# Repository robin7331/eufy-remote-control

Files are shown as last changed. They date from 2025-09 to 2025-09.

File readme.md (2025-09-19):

# Eufy Make Remote Control Button Box

This repository contains both the **software** and **hardware** files for the Eufy Make Remote Control Button Box project.

## Overview

- **Hardware**: Kicad PCB designs
- **Software**: MicroPython code for the RP2040 Stamp

## Connectivity

The button box is designed to connect to an **MQTT broker**.

---

For details, see the `hardware/` and `software/` folders.

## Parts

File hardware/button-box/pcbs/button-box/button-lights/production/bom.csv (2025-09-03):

Designator | Footprint | Quantity | Value | LCSC Part #
J1, J2 | CONN_SM04B-SRSS-TB_JST | 2 | SM04B-SRSS-TB
U1, U2, U3, U4 | LED_WS2812-2020 | 4 | WS2812-2020

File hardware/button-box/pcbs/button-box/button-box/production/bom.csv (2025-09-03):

Designator | Footprint | Quantity | Value | LCSC Part #
C1 | 0603 | 1 | 1n | 1n 0603
C2 | 0603 | 1 | 100n | 100n 0603
C3 | 0805 | 1 | 10u
D1, D2, D3 | SOT-23 | 3 | SP0502BAHT | SP0502BAHT
F1 | 1812 | 1 | 1812L150/24 | 1812L075PR
J1 | USB_C_Purple | 1 | HC-TYPE-C-16P-01A-L
J2 | CONN_SM04B-SRSS-TB_JST | 1 | SM04B-SRSS-TB
J3 | PinHeader_1x03_P2.54mm_Horizontal | 1 | Conn_01x03_Pin
L1 | L_TDK_SLF7032 | 1 | 6.8uH | SLF7032T-6R8M1R6-2-PF
Q1, Q2 | SOT-23 | 2 | onsemi NTR4503NT1G | NTR4503NT1G
R1, R11, R13, R5 | 0603 | 4 | 10k | 10k 0603
R10 | 0603 | 1 | 470 | 1M 0603
R12 | 0603 | 1 | 10k | 1M 0603
R2 | 0603 | 1 | 1M | 1M 0603
R3, R4 | 0603 | 2 | 0
R6, R8 | 0603 | 2 | 12k | 1M 0603
R7 | 0603 | 1 | 5.1k | 5.1k 0402
R9 | 0603 | 1 | 5.1k | 5.1k 0603
SW1, SW2 | SW_MX_LowProfile_THT | 2 | SW_Push
U1 | rpi_rmc20452t | 1 | RP Wireless Module 2
U2 | RP2xxx_Stamp_SMD | 1 | RP2040_Stamp

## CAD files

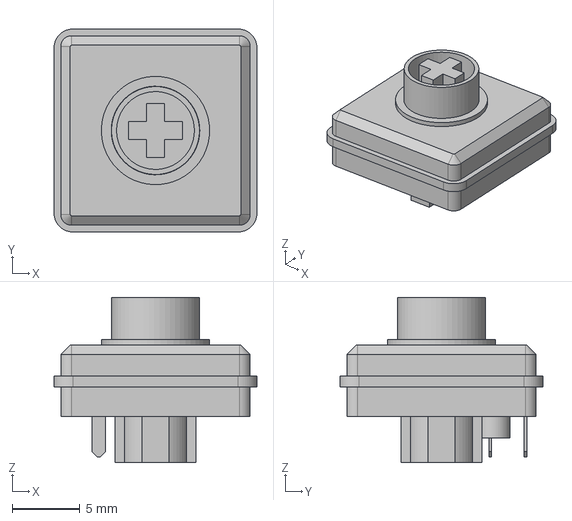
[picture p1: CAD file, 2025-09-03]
hardware/button-box/pcbs/button-box/button-box/components/cherry-mx-low-profile/[low detail] Low Profile Cherry MX Red.step
15.0 x 15.0 x 12.2 mm

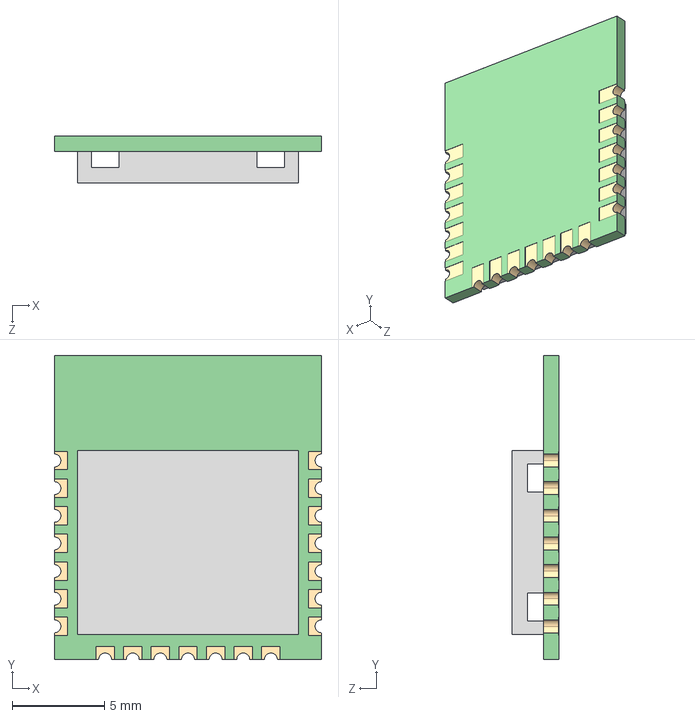
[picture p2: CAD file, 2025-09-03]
hardware/button-box/pcbs/button-box/button-box/components/raspberry-wireless-module-2/3d_models/rpi_rmc20452t.step
14.5 x 16.5 x 2.55 mm

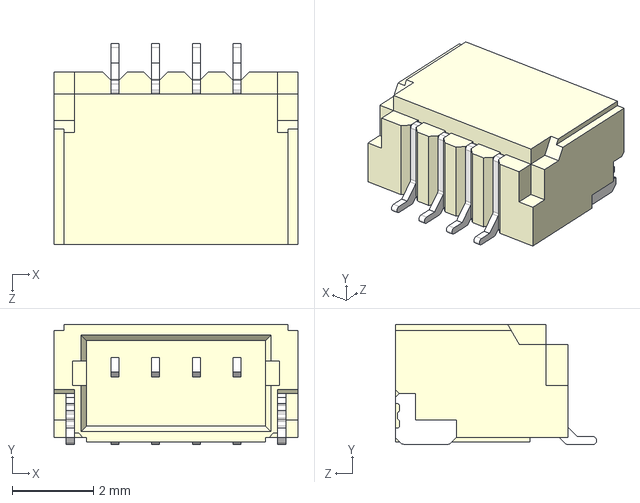
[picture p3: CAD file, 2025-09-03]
hardware/button-box/pcbs/button-box/button-box/components/SM04B-SRSS-TB/SM04B-SRSS-TB.step
6.00 x 2.96 x 4.95 mm

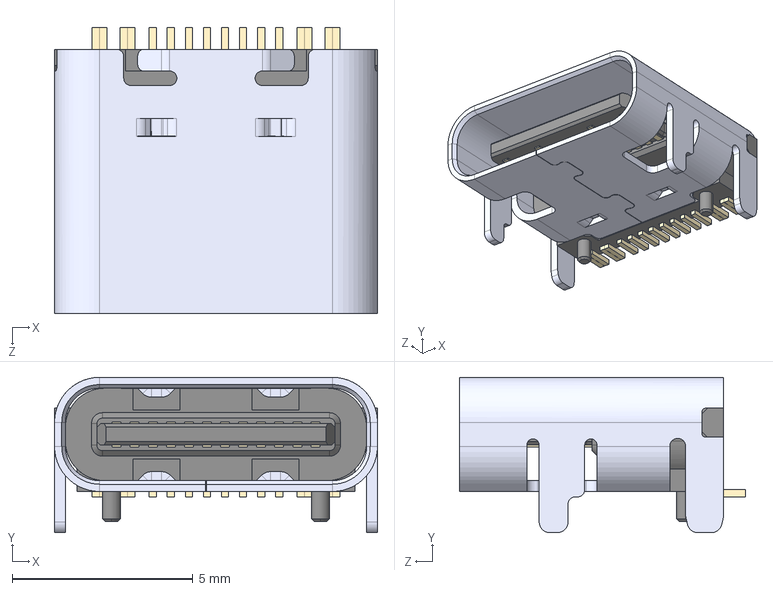
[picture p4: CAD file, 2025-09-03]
hardware/button-box/pcbs/button-box/button-box/components/USB-C/TYPE-C-31-M-12--3DModel-STEP-56544.STEP
8.94 x 4.30 x 7.90 mm

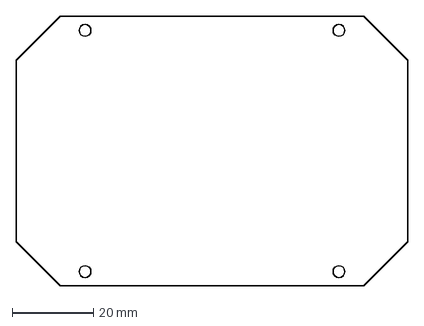
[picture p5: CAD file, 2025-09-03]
hardware/button-box/pcbs/button-box/button-box/fusion-export/Outline.dxf
96.4 x 66.4 mm

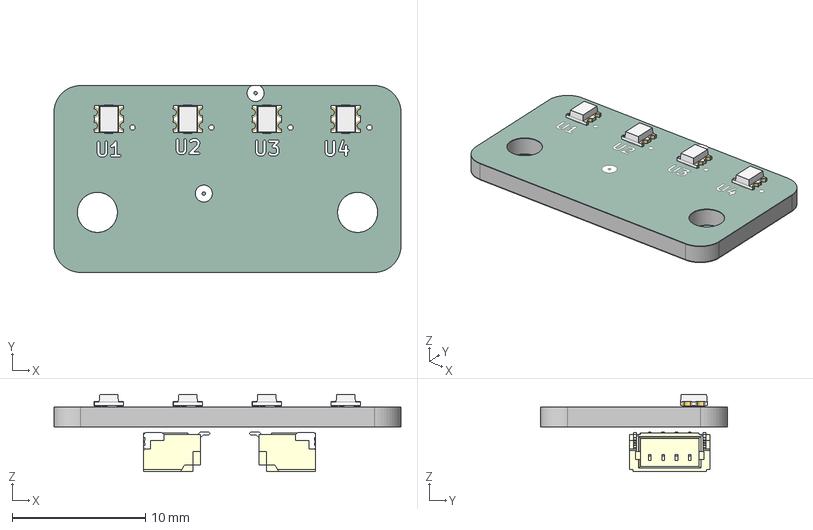
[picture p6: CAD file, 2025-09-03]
hardware/button-box/pcbs/button-box/button-lights/button-lights.step
26.0 x 14.0 x 5.79 mm
WS2812-2020 x 4
SM04B-SRSS-TB x 2
button-lights_silkscreen
button-lights_soldermask
button-lights_PCB

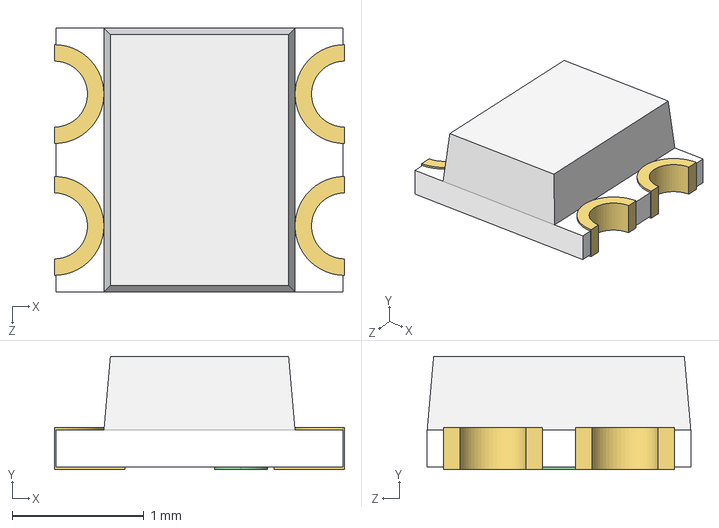
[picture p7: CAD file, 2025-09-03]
hardware/button-box/pcbs/button-box/button-lights/components/WS2812-2020/WS2812-2020.STEP
2.20 x 0.86 x 2.00 mm

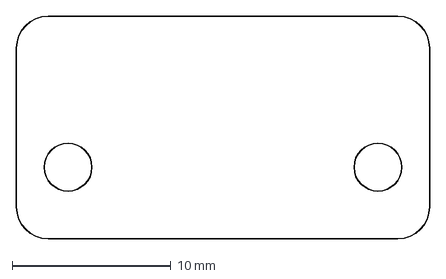
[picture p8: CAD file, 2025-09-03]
hardware/button-box/pcbs/button-box/button-lights/fusion-export/Outline.dxf
26.0 x 14.0 mm

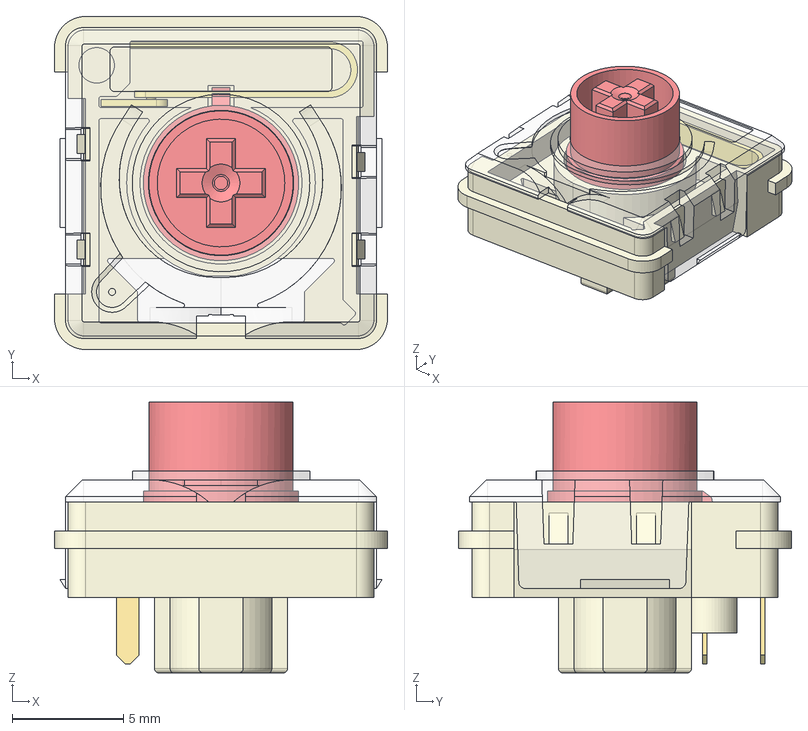
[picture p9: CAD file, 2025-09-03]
hardware/button-box/pcbs/button-box/button-box/components/cherry-mx-low-profile/[high detail] Low Profile Cherry MX Red.step
15.0 x 15.0 x 12.2 mm
Stem
Top Case
Bottom Case
Spring

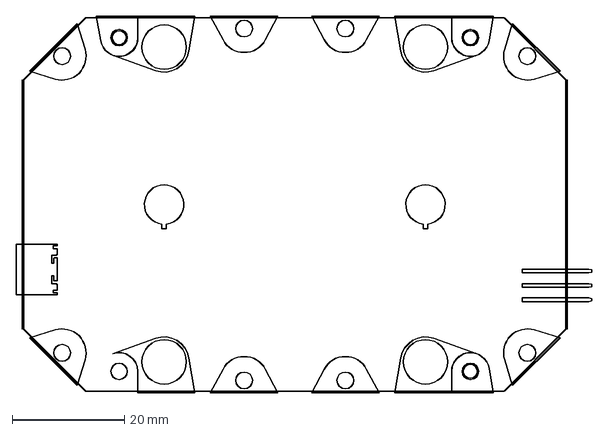
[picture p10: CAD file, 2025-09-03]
hardware/button-box/pcbs/button-box/button-box/fusion-export/User Drawings.dxf
102.4 x 67.0 mm

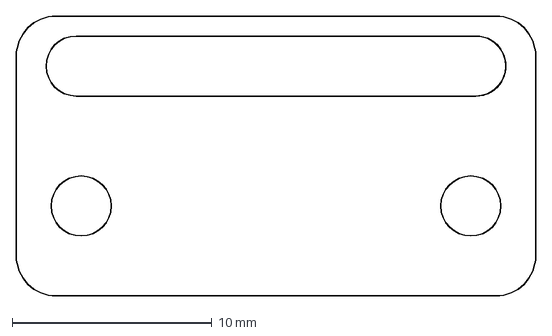
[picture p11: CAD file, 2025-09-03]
hardware/button-box/pcbs/button-box/button-lights/fusion-export/Drawings.dxf
26.0 x 14.0 mm

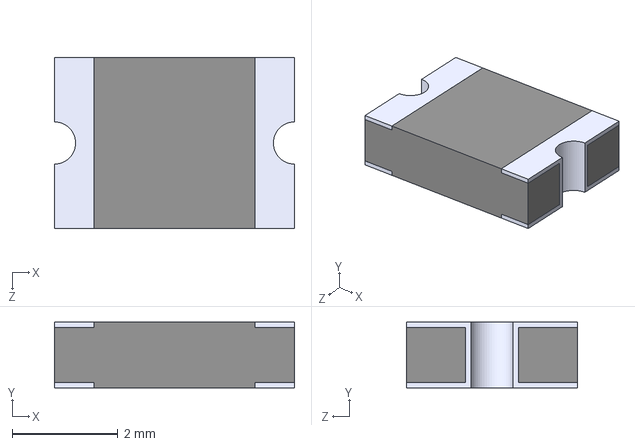
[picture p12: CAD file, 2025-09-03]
hardware/button-box/pcbs/button-box/button-box/components/1812L150_24.STEP
4.55 x 1.25 x 3.24 mm

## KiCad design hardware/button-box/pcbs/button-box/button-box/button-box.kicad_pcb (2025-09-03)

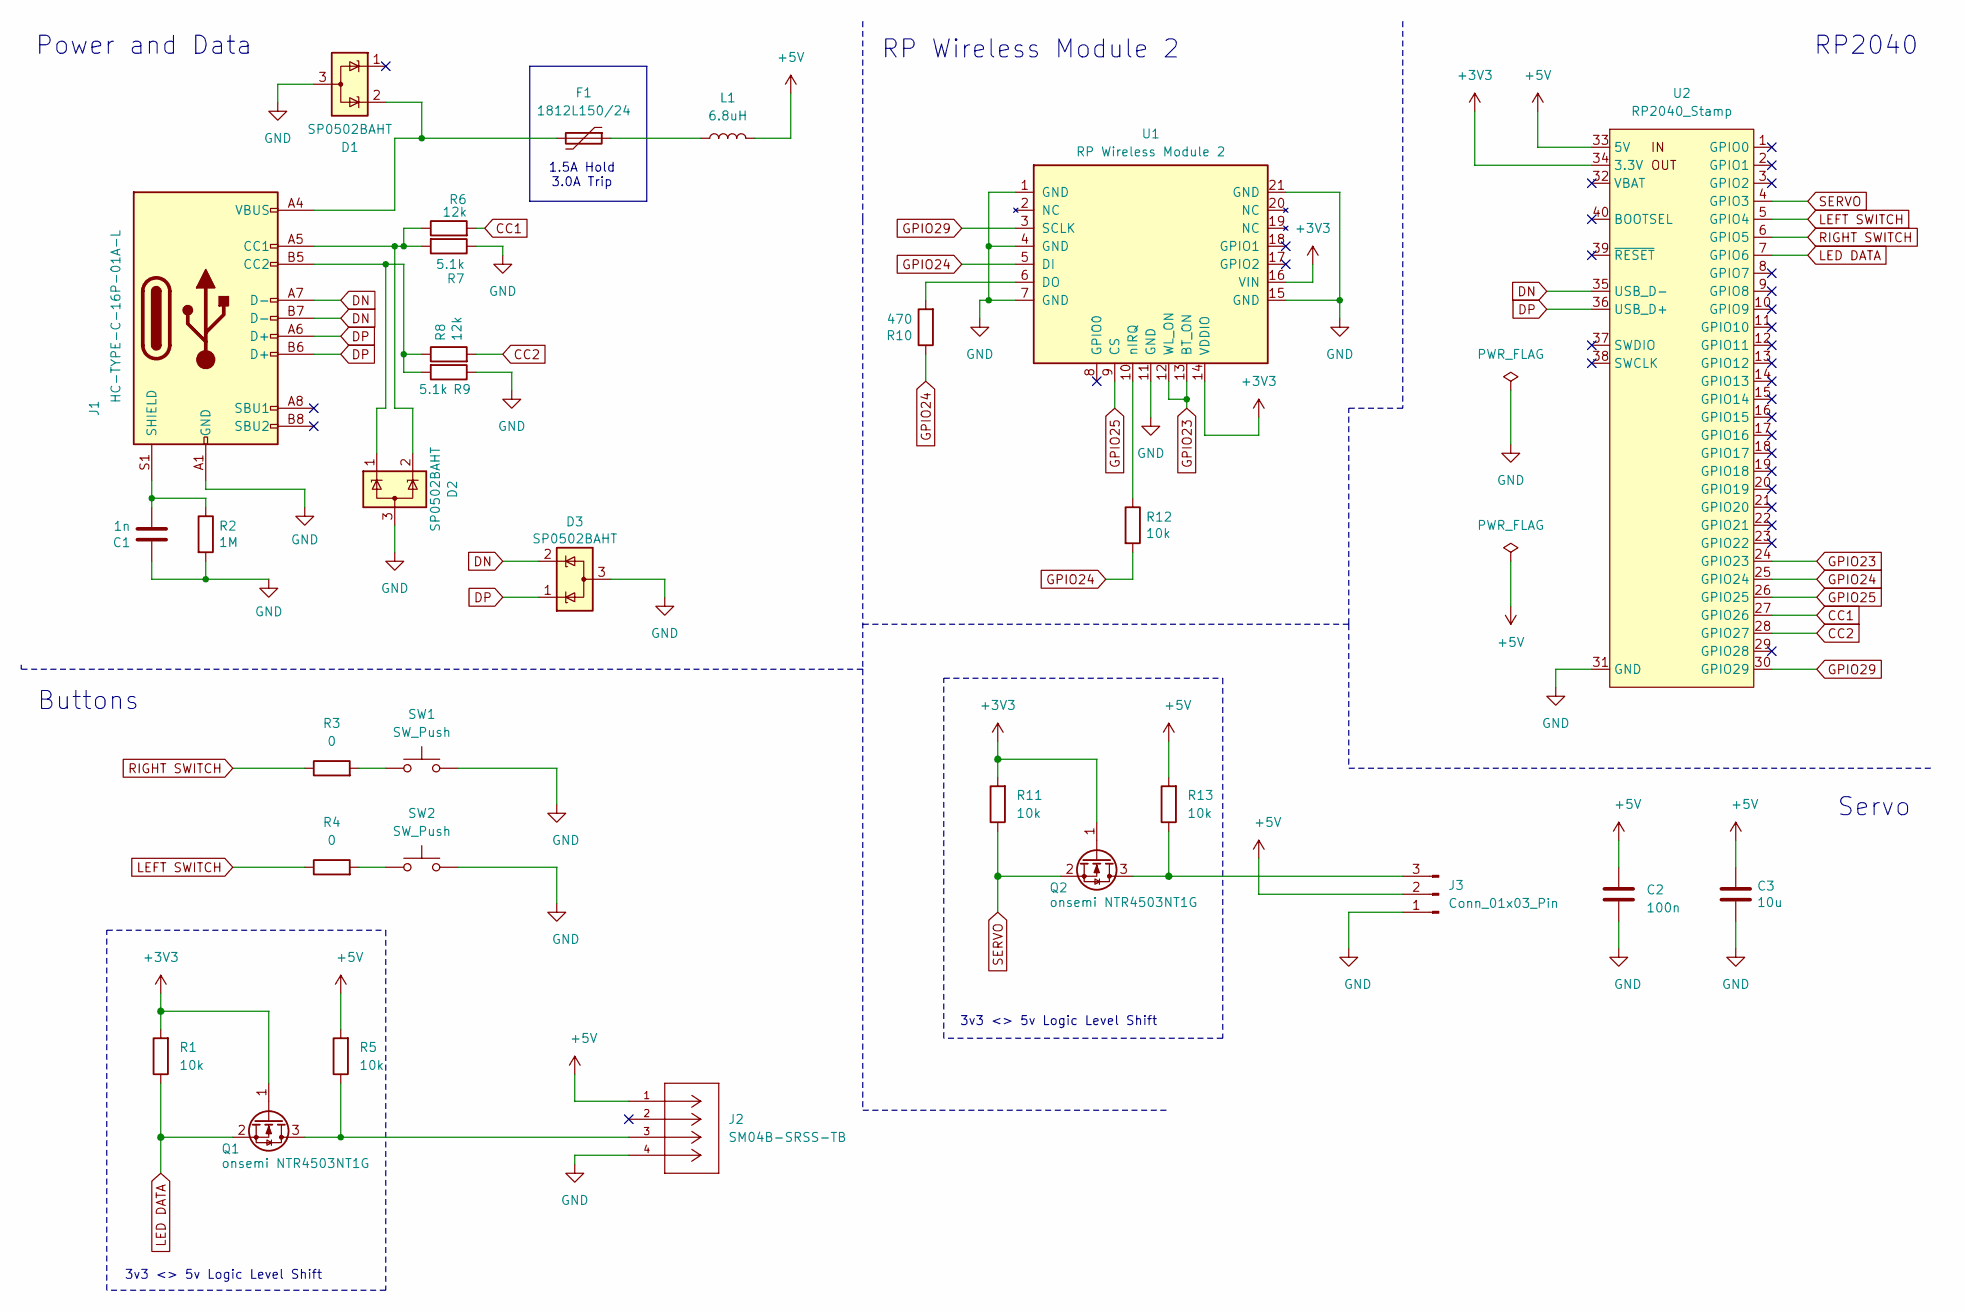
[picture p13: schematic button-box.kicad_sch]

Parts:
C1: 1n; C_0603_1608Metric; MPN 1n 0603
C2: 100n; C_0603_1608Metric; MPN 100n 0603
C3: 10u; C_0805_2012Metric
D1, D2, D3: SP0502BAHT; SOT-23; MPN SP0502BAHT
F1: 1812L150/24; Fuse_1812_4532Metric; MPN 1812L075PR
J1: HC-TYPE-C-16P-01A-L; USB_C_Purple
J2: SM04B-SRSS-TB; CONN_SM04B-SRSS-TB_JST; MANUFACTURER_PART_NUMBER SM04B-SRSS-TB
J3: Conn_01x03_Pin; PinHeader_1x03_P2.54mm_Horizontal
L1: 6.8uH; L_TDK_SLF7032; MPN SLF7032T-6R8M1R6-2-PF
Q1, Q2: onsemi NTR4503NT1G; SOT-23; MPN NTR4503NT1G
R1, R5, R11, R13: 10k; R_0603_1608Metric; MPN 10k 0603
R2: 1M; R_0603_1608Metric; MPN 1M 0603
R3, R4: 0; C_0603_1608Metric
R6, R8: 12k; R_0603_1608Metric; MPN 1M 0603
R7: 5.1k; R_0603_1608Metric; MPN 5.1k 0402
R9: 5.1k; R_0603_1608Metric; MPN 5.1k 0603
R10: 470; R_0603_1608Metric; MPN 1M 0603
R12: 10k; R_0603_1608Metric; MPN 1M 0603
SW1, SW2: SW_Push; SW_MX_LowProfile_THT
U1: RP Wireless Module 2; rpi_rmc20452t
U2: RP2040_Stamp; RP2xxx_Stamp_SMD

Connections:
+3V3: Q1.1 (G), Q2.1 (G), R1.2, R11.2, U1.14 (VDDIO), U1.16 (VIN), U2.34 (3.3V)
+5V: C2.1, C3.1, J2.1, J3.2, L1.2, R5.2, R13.2, U2.33 (5V)
CC1: R6.2, U2.27 (GPIO26)
CC2: R8.2, U2.28 (GPIO27)
DN: D3.2 (K), J1.A7 (D-), J1.B7 (D-), U2.35 (USB_D-)
DP: D3.1 (K), J1.A6 (D+), J1.B6 (D+), U2.36 (USB_D+)
GND: C1.1, C2.2, C3.2, D1.3 (A), D2.3 (A), D3.3 (A), J1.A1 (GND), J1.A12 (GND), J1.B1 (GND), J1.B12 (GND), J2.4, J3.1, R2.2, R7.1, R9.1, SW1.2, SW2.2, U1.1 (GND), U1.4 (GND), U1.7 (GND), U1.11 (GND), U1.15 (GND), U1.21 (GND), U2.31 (GND)
GPIO23: U1.12 (WL_ON), U1.13 (BT_ON), U2.24 (GPIO23)
GPIO24: R10.1, R12.2, U1.5 (DI), U2.25 (GPIO24)
GPIO25: U1.9 (CS), U2.26 (GPIO25)
GPIO29: U1.3 (SCLK), U2.30 (GPIO29)
LED DATA: Q1.2 (S), R1.1, U2.7 (GPIO6)
LEFT SWITCH: R4.1, U2.5 (GPIO4)
unnamed: D1.2 (K), F1.2, J1.A4 (VBUS), J1.A9 (VBUS), J1.B4 (VBUS), J1.B9 (VBUS)
unnamed: F1.1, L1.1
unnamed: D2.2 (K), J1.A5 (CC1), R6.1, R7.2
unnamed: D2.1 (K), J1.B5 (CC2), R8.1, R9.2
unnamed: C1.2, J1.S1 (SHIELD), R2.1
unnamed: J3.3, Q2.3 (D), R13.1
unnamed: J2.3, Q1.3 (D), R5.1
unnamed: R3.2, SW1.1
unnamed: R4.2, SW2.1
unnamed: R10.2, U1.6 (DO)
unnamed: R12.1, U1.10 (nIRQ)
RIGHT SWITCH: R3.1, U2.6 (GPIO5)
SERVO: Q2.2 (S), R11.1, U2.4 (GPIO3)

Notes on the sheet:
3v3 <> 5v Logic Level Shift
RP2040
Power and Data
Servo
Buttons
RP Wireless Module 2
1.5A Hold 3.0A Trip

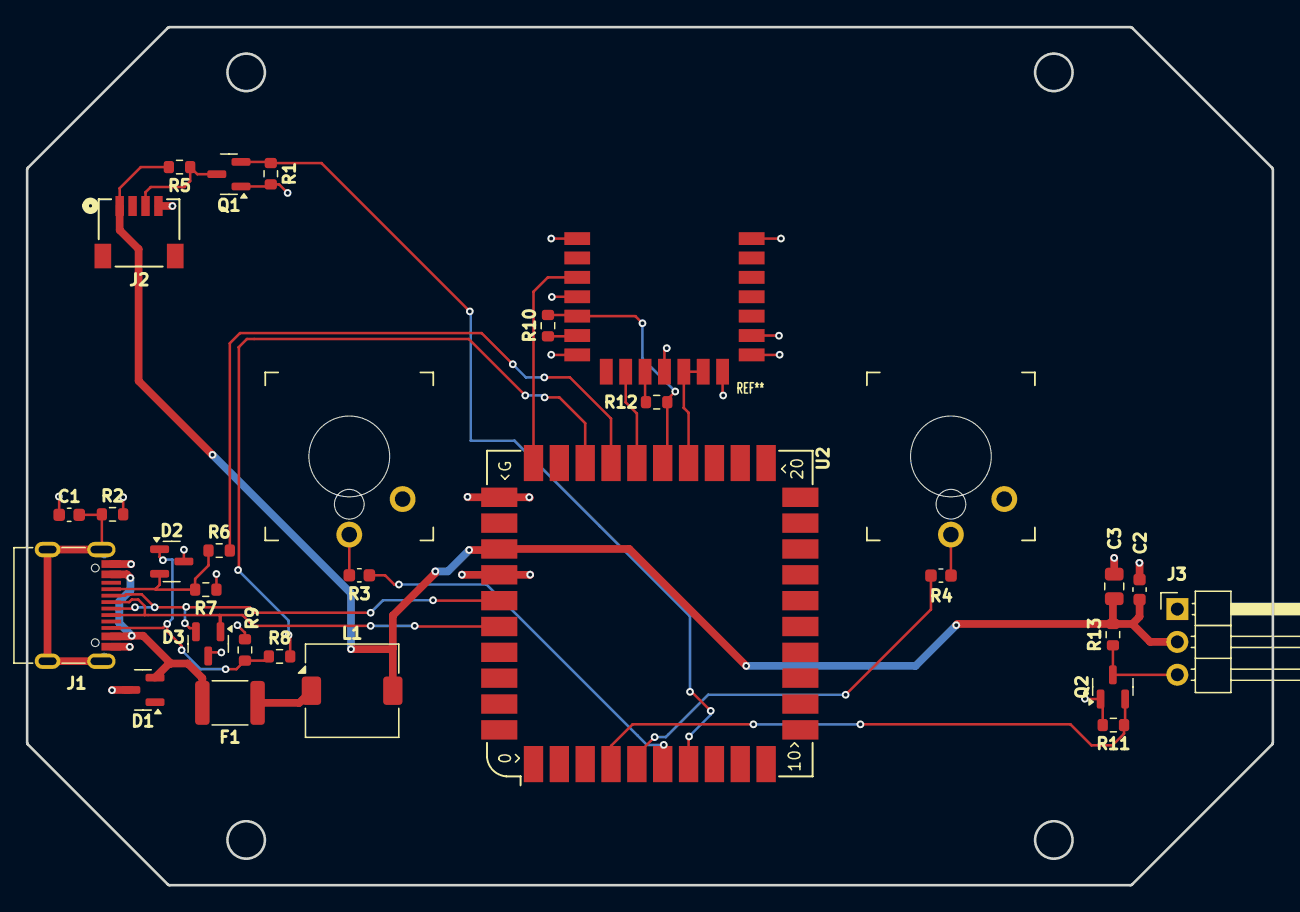
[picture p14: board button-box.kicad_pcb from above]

Board: 4 copper layers, 96.4 x 66.4 mm, 30 parts (0 on the bottom side), 26 nets.

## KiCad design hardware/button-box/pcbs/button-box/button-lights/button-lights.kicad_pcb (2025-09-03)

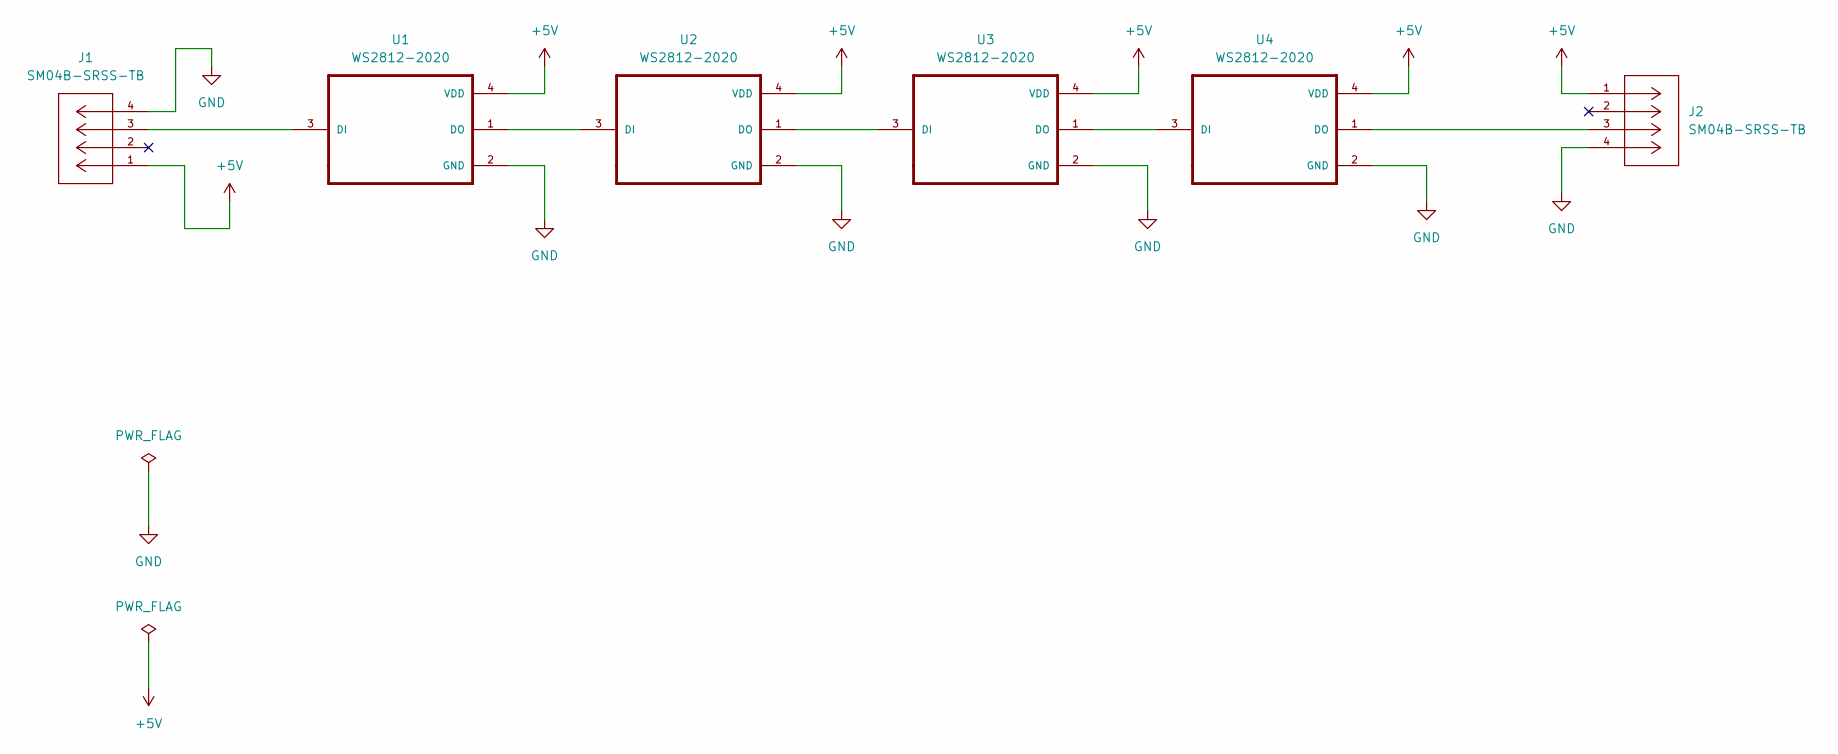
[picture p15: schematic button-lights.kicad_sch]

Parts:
J1, J2: SM04B-SRSS-TB; CONN_SM04B-SRSS-TB_JST; MANUFACTURER_PART_NUMBER SM04B-SRSS-TB
U1, U2, U3, U4: WS2812-2020; LED_WS2812-2020

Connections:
+5V: J1.1, J2.1, U1.4 (VDD), U2.4 (VDD), U3.4 (VDD), U4.4 (VDD)
GND: J1.4, J2.4, U1.2 (GND), U2.2 (GND), U3.2 (GND), U4.2 (GND)
unnamed: J1.3, U1.3 (DI)
unnamed: U1.1 (DO), U2.3 (DI)
unnamed: U2.1 (DO), U3.3 (DI)
unnamed: U3.1 (DO), U4.3 (DI)
unnamed: J2.3, U4.1 (DO)

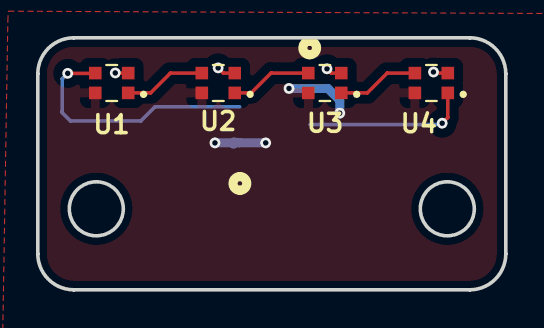
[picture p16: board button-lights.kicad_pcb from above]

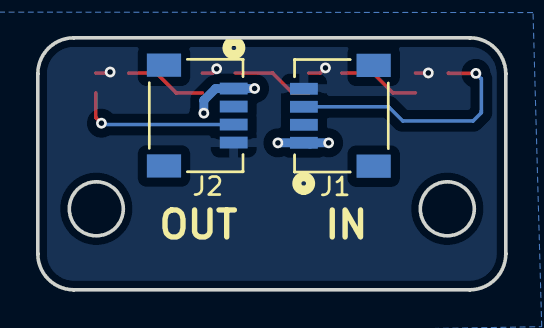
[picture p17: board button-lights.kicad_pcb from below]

Board: 2 copper layers, 26.0 x 14.0 mm, 6 parts (2 on the bottom side), 7 nets.

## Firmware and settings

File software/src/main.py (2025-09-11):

import machine

from time import sleep
import machine
import ujson
from ui_renderer import UIRenderer
from boot_sequence import run_boot_sequence
from machine import Timer
import utime
from controls.io_event_source import IOEventSource
from controls.io_event import IOEvent
from controls.illumination import Illumination
from controls.tapper import Tapper
from device import Device
from connection_manager import ConnectionManager, ConnectionState, PingState
import asyncio


# MQTT Broker details
BROKER_IP = '192.168.4.167'
BROKER_PORT = 1883
STATUS_TOPIC = 'uv_studio/status'
COMMAND_TOPIC = 'uv_studio/command'
CONTROL_TOPIC = 'uv_studio/control'

machine.freq(96000000)

# The UI Renderer class holds the frame buffer and the PIO state machine
renderer = UIRenderer(brightness_modifier=1.0, led_pin=6, led_count=8)



# Lets render the buttons at 30 fps (just for the boot sequence)
uiTimer = Timer()
uiTimer.init(freq=30, mode=Timer.PERIODIC,
             callback=lambda t: renderer.flush_frame_buffer())
# # Lets run a fancy rainbow boot sequence
run_boot_sequence(renderer, led_count=8, brightness=0.8)
uiTimer.deinit()


def renderIllumination(entity):
    global renderer
    for led_index in entity.led_indexes:
        renderer.set_led_color(
            led_index, (entity.color[0], entity.color[1], entity.color[2]), entity.color[3])

left_button_illumination = Illumination(led_indexes=[4,5,6,7], on_should_render=renderIllumination)    
right_button_illumination = Illumination(led_indexes=[0,1,2,3], on_should_render=renderIllumination)    

left_button_illumination.set_color((0, 0, 0), 0.0, animated=False)
right_button_illumination.set_color((0, 0, 0), 0.0, animated=False)

tapper = Tapper()

device = Device(left_illumination=left_button_illumination, right_illumination=right_button_illumination, tapper=tapper)



def connection_cb(connection_manager, state):
    print('Connection state changed to: %s' % state)
    if state is ConnectionState.ERROR:
        device.to_error()

def on_ping(connection_manager, state):
    print('Ping state changed to: %s' % state)
    if state is PingState.PRINTING_12MM:
        device.to_printing(type='12mm')

    if state is PingState.PRINTING_16MM:
        device.to_printing(type='16mm')

    if state is PingState.ERROR_12MM:
        device.to_error(type='12mm')

    if state is PingState.ERROR_16MM:
        device.to_error(type='16mm')

    if state is PingState.TIMEOUT:
        device.to_timeout()

    if state is PingState.IDLE: 
        device.to_idle()


def left_button_tapped(source):
    global connection_manager
    if device.is_idle() or device.is_error():
        connection_manager.send_mqtt_command('start_12mm_print')
    else: 
        print('Not in idle state, ignoring button press')


def right_button_tapped(source):
    global connection_manager
    if device.is_idle() or device.is_error():
        connection_manager.send_mqtt_command('start_16mm_print')
    else: 
        print('Not in idle state, ignoring button press')

def stop(source):
    global connection_manager
    connection_manager.send_mqtt_command('stop')

def set_tapper_parameters(retracted_angle, extended_angle):
    tapper.retracted_angle = retracted_angle
    tapper.extended_angle = extended_angle


left_button = IOEventSource(title='Left Button', pin_number=4, pin_mode=machine.Pin.IN, pin_pull=machine.Pin.PULL_UP, invert=True, on_tapped=left_button_tapped, on_long_hold=stop)
right_button = IOEventSource(title='Right Button', pin_number=5, pin_mode=machine.Pin.IN, pin_pull=machine.Pin.PULL_UP, invert=True, on_tapped=right_button_tapped, on_long_hold=stop)

connection_manager = ConnectionManager(BROKER_IP, BROKER_PORT)
connection_manager.set_on_connection_changed(connection_cb)
connection_manager.set_on_trigger_servo(lambda: tapper.tap())
connection_manager.set_on_ping_changed(on_ping)
connection_manager.set_on_servo_parameters_received(set_tapper_parameters)

asyncio.run(connection_manager.connect())

# We are ready!
left_button_illumination.flash((0, 255, 0), 0.28)
right_button_illumination.flash((0, 255, 0), 0.28)

last_rendered_at = utime.ticks_ms()

while True:       
    left_button.tick()
    left_button_illumination.tick()

    right_button.tick()
    right_button_illumination.tick()

    device.tick(utime.ticks_ms())

    connection_manager.tick()

    tapper.tick()

    # Render the UI at 30 FPS.
    if utime.ticks_ms() - last_rendered_at > 33:
        renderer.flush_frame_buffer()
        last_rendered_at = utime.ticks_ms()

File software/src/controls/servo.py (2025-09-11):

import machine
import math

class Servo:
    def __init__(self,pin_id,min_us=550,max_us=2450,min_deg=0.0,max_deg=180.0,freq=50):
        self.pwm = machine.PWM(machine.Pin(pin_id))
        self.pwm.freq(freq)
        self.current_us = 0.0
        self._slope = (min_us-max_us)/(math.radians(min_deg)-math.radians(max_deg))
        self._offset = min_us
        
    def write(self,deg):
        self.write_rad(math.radians(deg))

    def read(self):
        return math.degrees(self.read_rad())
        
    def write_rad(self,rad):
        self.write_us(rad*self._slope+self._offset)
    
    def read_rad(self):
        return (self.current_us-self._offset)/self._slope
        
    def write_us(self,us):
        self.current_us=us
        self.pwm.duty_ns(int(self.current_us*1000.0))
    
    def read_us(self):
        return self.current_us

    def off(self):
        self.pwm.duty_ns(0)

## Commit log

2025-09-03 pcb ordered
    [1812L150_24.STEP, Drawings.dxf, Outline.dxf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]
2025-09-11 Generate Bom
2025-09-19 generated bom

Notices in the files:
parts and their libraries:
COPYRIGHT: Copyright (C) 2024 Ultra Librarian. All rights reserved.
